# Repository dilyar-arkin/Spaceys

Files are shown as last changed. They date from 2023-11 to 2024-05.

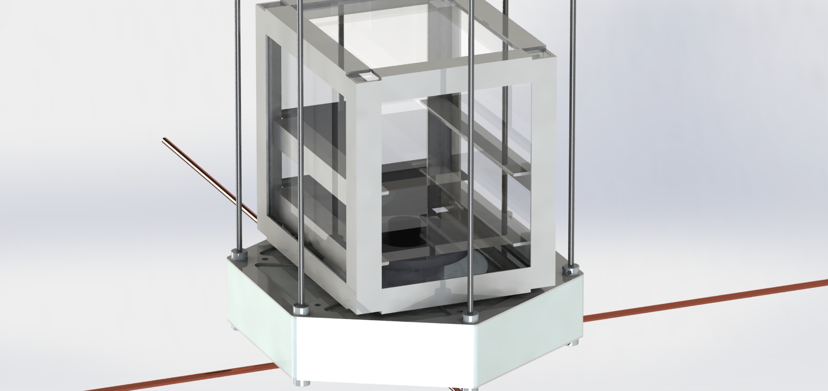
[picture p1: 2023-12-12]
Images/preview04.JPG

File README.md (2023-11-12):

# Spaceys
High Altitude RF Transmission Project

## Milestone 1
### On Board Sensor Integration 
To aquire data from following sensors and save them on micro SD card  via Raspberry Pi. 
* Gyroscope integration
* Thermocouple integration
* Pressure sensor integration

### CAD Modelling
* Assembly model for polycarbonate box
* Bill of materials for structural parts
* mock up 3D models for electronics components within the assembly
* mock up model for dipole antennas incl. supporing parts
* insulation layers both inner and outer

## Milestone 2
### Risk Analysis
* Fill up form:  CSA-STRATOS-FORM-0010_rev_IR_-_SEB_PAYLAOD_QT
### Software Defined Radio
* setup HackRF to receive FM radio stations
* Setup radiating element in the lab by signal generator, receiving signal on HackRF
* get familiar with bandpass filters, attunuation, and other aspacts of SDR
### Payload Safety Control 
* integrate heating and cooling devices into the payload for temperature control
* add event driven temperature / pressure control software functions to activate heaters/coolers
* thermal analysis on transfer layers to optimize shielding electronics from extreme environment  

## Milestone 3
### Transmitter RF Design and Development
* Signal generation - define equipment type specs
* RF amplifier - can handle output power level from signal generator and outputs 50 watts or higher Tx power
* Antenna impedance matching with the internal electronics. (antenna tuning)
* Design/Fabtication/Installation of the transmitter antenna module (50 ohms internal impedance)
* integrate Tx antenna into payload box, mounting and assembling
* Testing for weather, impact, shock (mechanical testing)
* Testing for beam forms, attenuation, gain, signal strength and more (electronic testing)

## Milestone 4
### Receiver RF - Ground Station Design and Development
* Rx antenna design and development (mechanical structure, impedance matching, gain ...)
* Antenna to Hack RF integration
* Software development (noise filtering, analog to digital conversion, frequency domain analysis ...)
* Modularity (ease of transport, palican case storage)

## Milestone 5
### Mechanical Testing
### Electrical Testing
### Software Testing
### RF Signal Range Testing

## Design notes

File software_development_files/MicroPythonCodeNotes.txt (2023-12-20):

SPACEY's MicroPython Code Notes
Michael Burns

i2c

from machine import Pin, I2C

i2c = I2C(0, scl=Pin(9), sda=Pin(8), freq=100000) 
i2c.scan()
i2c.writeto(76, b'123')
i2c.readfrom(76, 4)

i2c = I2C(1, scl=Pin(7), sda=Pin(6), freq=100000)
i2c.scan()
i2c.writeto_mem(76, 6, b'456')
i2c.readfrom_mem(76, 6, 4)

adc temperature

import machine
import utime

sensor_temp = machine.ADC(4)
conversion_factor = 3.3 / (65535)

while True:
    reading = sensor_temp.read_u16() * conversion_factor
    
    # The temperature sensor measures the Vbe voltage of a biased bipolar diode, connected to the fifth ADC channel
    # Typically, Vbe = 0.706V at 27 degrees C, with a slope of -1.721mV (0.001721) per degree. 
    temperature = 27 - (reading - 0.706)/0.001721
    print(temperature)
    utime.sleep(2)

Preliminary code attempt for sensor data collection based on the above example code.

import machine
import utime
from machine import Pin, I2C   #Imported relevant libraries and packages. 

#Code attempt for Pololu Gyro sensor connected to the first and second GPIO pins (I2C0 SDA) and (I2C0 SCL), respectively. 
i2c = I2C(0, scl=Pin(1), sda=Pin(0), freq=100)
i2c.scan()
i2c.writeto(76, b'123')  #Id like to look up the call sequence for these later for the significance of the 76 and the b'123'.
i2c.readfrom(76, 4)

#Code attempt for BMP 280 Pressure Sensor connected to the fourth and fifth GPIO pins (I2C1 SDA) and (I2C1 SCL), respectively.
i2c = I2C(1, scl=Pin(4), sda=Pin(3), freq=100)
i2c.scan()
i2c.writeto_mem(76, 6, b'456')
i2c.readfrom_mem(76, 6, 4)

#Code attempt for the temperature sensor connected to the 31st GPIO pin (ADC0). 
sensor_temp = machine.ADC(0)
conversion_factor = 3.3 / (65535)

while True;
    reading = sensor_temp.read_u16() * conversion_factor
    
    #Measuring the Vbe voltage of the diode, connected to the first ADC channel.
    #From example code; usually Vbe = 0.706V at 27 degrees C, with a slope of -1.721mV per degree.
    temperature = 27 - (reading - 0.706)/0.001721
    print(temperature)
    utime.sleep(2)

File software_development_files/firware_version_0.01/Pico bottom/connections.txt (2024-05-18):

-big SD
-gyroscope sensor
-temperature sensor connected to the Peltier cooler: GPIO28
-temperature sensor: GPIO27
-relay

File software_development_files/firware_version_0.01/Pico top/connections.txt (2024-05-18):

-microSD
-BMP280 pressure sensor
-temperature sensor: GPIO 26
-temperature sensor: GPIO 22

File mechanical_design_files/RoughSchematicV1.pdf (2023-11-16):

1* 30":T'#
1l-''

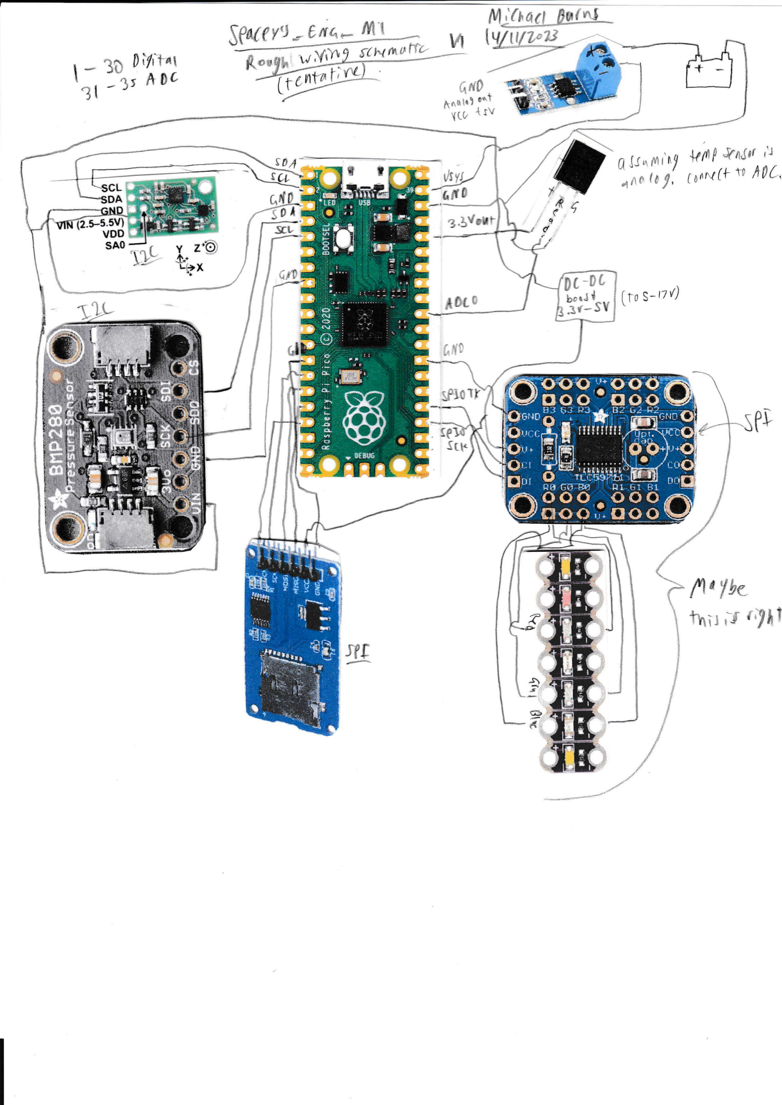
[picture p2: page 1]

## TPa{f v'i - {rt{^* ffi.1

L)\ - *' | -*- | :

### SD A- <':: lar \t

## c4!: r'To I t

Yr

scL i

it flU 'I
trnuhl Git
{(-0 I sv

&,r0
3.5{c*r

## t0r c

### fi JJ o rrr i't/

,{ne fdf,

kdf *Fn,jcr r)
66rrM(t \il A0L,

Dt -0[
bcrJ { (to s-iz'r)
.:r-5Y

: ".,.
!\

# rricrl

.5ri
{e
5rF

(
F nd Y&*-

## %i: ;g {'f &?

A

{B

## zts

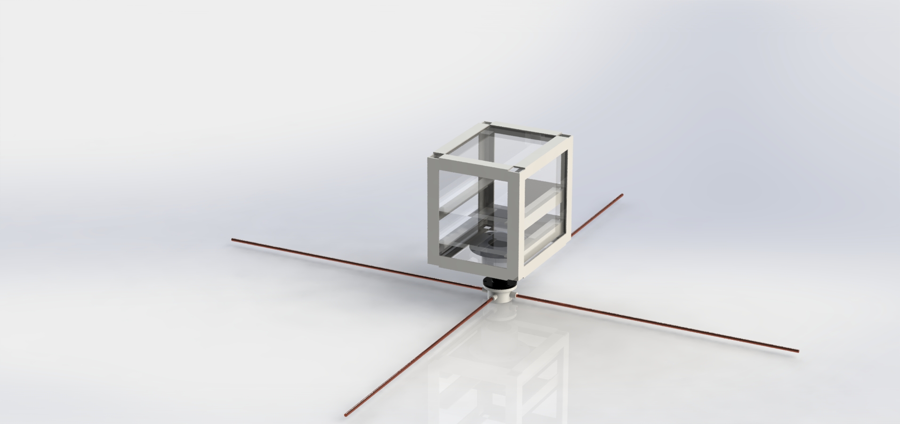
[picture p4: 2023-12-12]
Images/preview01.JPG

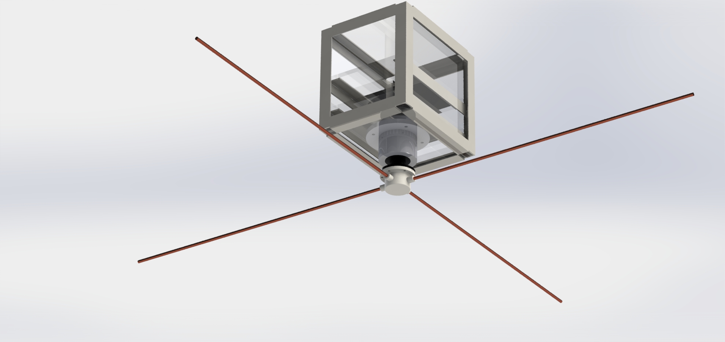
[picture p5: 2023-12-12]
Images/preview02.JPG

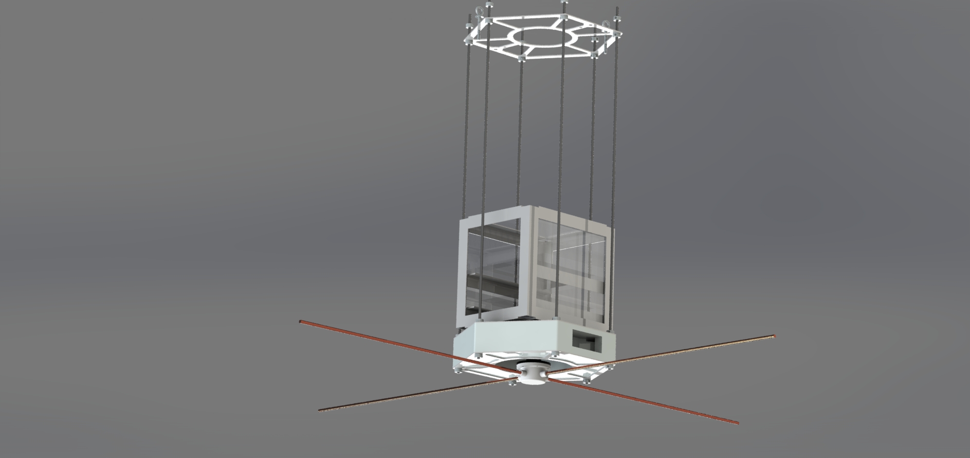
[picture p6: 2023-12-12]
Images/preview05.JPG

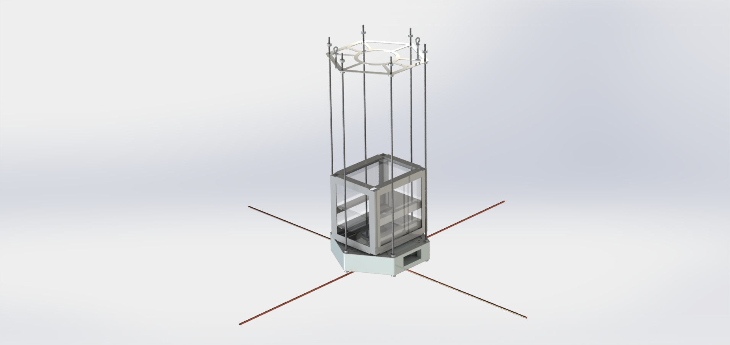
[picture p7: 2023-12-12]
Images/preview03.JPG

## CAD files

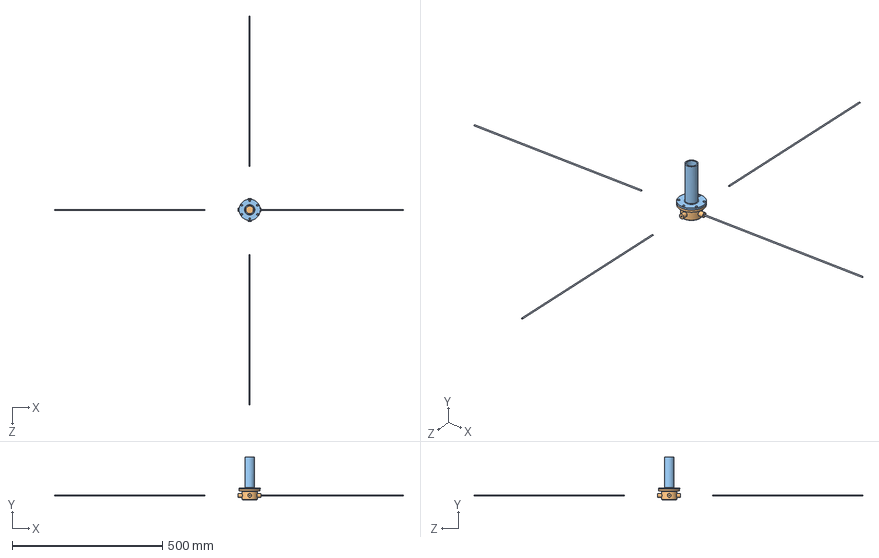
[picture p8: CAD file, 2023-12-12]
mechanical_design_files/CAD model/antenna_housing_assem.SLDASM
1160.0 x 141.3 x 1291.8 mm
connector_arm
four_way_antennaHousing
radiating_element x 4

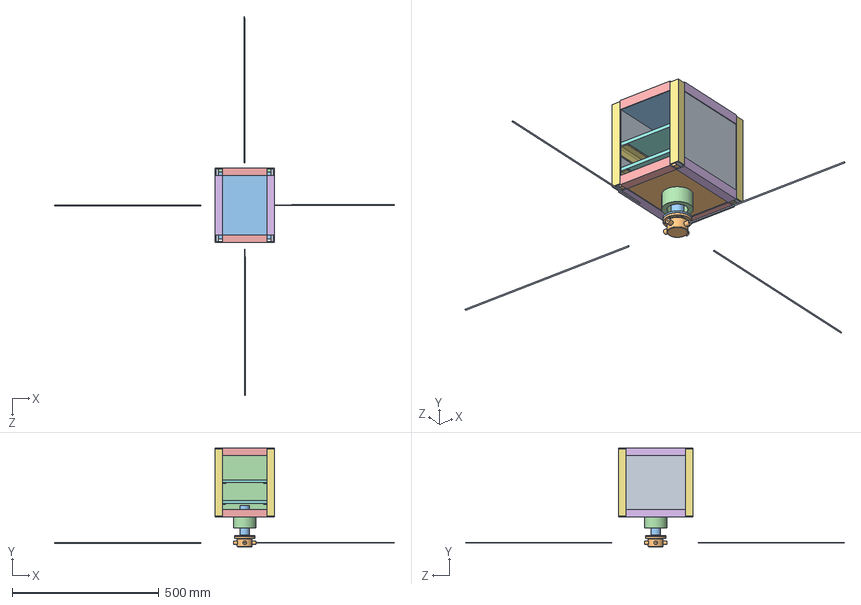
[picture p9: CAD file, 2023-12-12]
mechanical_design_files/CAD model/box_assembly.SLDASM
1160.0 x 337.3 x 1291.8 mm
cover_side
cover_top
cover_bottom
cover_side_long x 2
layer_base_plate x 2
8982K131_Multipurpose 6061 Aluminum 90 Degree Angle x 8
8982K131_Multipurpose 6061 Aluminum 90 Degree Angle_10inch_customCut x 4
8982K131_Multipurpose 6061 Aluminum 90 Degree Angle_8inch_customCut x 4
antenna_mount_bushing
connector_arm
four_way_antennaHousing
radiating_element x 4

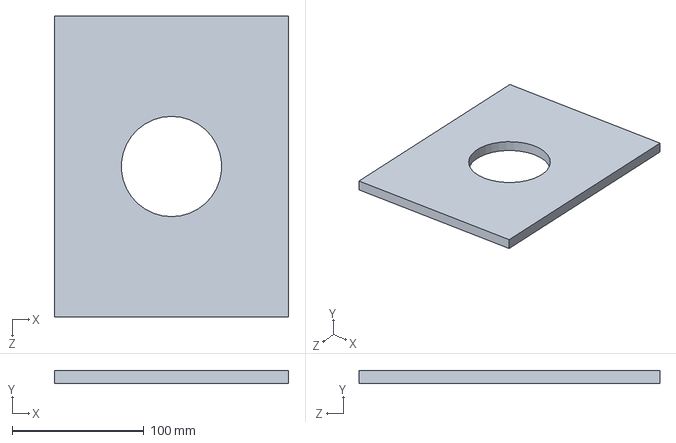
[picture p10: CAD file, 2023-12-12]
mechanical_design_files/CAD model/cover_bottom.SLDPRT
177.8 x 9.53 x 228.6 mm

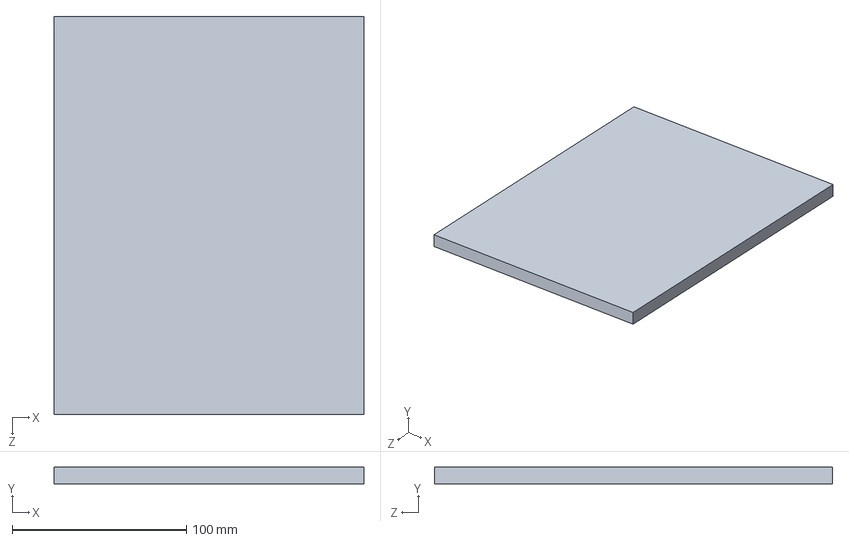
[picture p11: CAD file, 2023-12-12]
mechanical_design_files/CAD model/cover_top.SLDPRT
177.8 x 9.53 x 228.6 mm

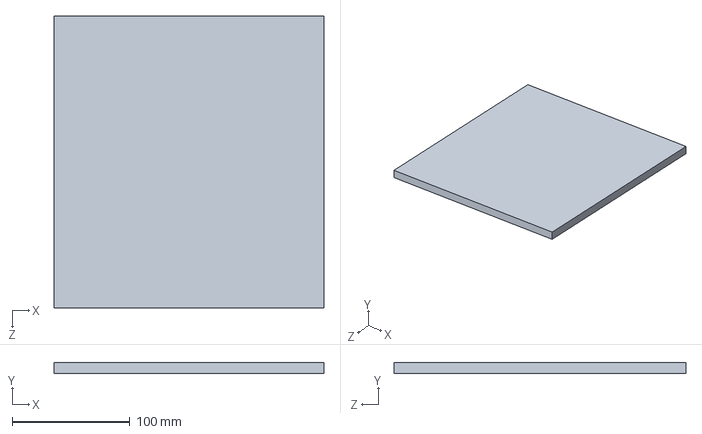
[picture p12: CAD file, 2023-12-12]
mechanical_design_files/CAD model/cover_side_long.SLDPRT
228.6 x 9.53 x 247.6 mm

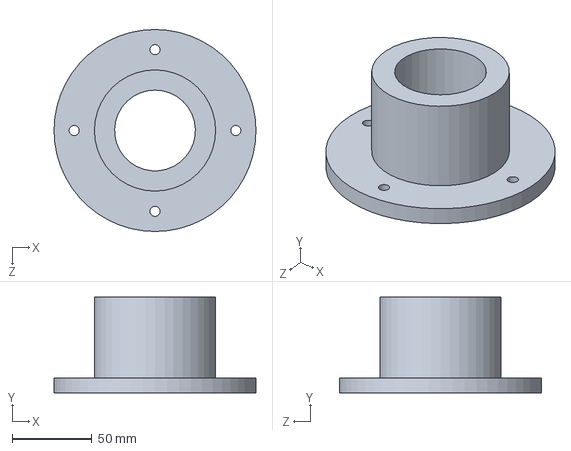
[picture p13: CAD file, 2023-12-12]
mechanical_design_files/CAD model/antenna_mount_bushing.SLDPRT
127.0 x 60.3 x 127.0 mm

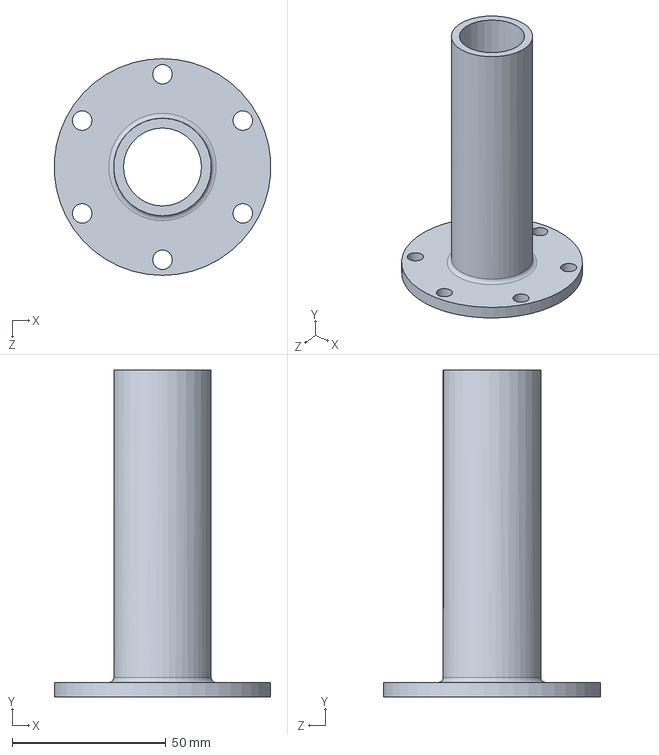
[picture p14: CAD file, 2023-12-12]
mechanical_design_files/CAD model/connector_arm.SLDPRT
70.3 x 106.4 x 70.5 mm

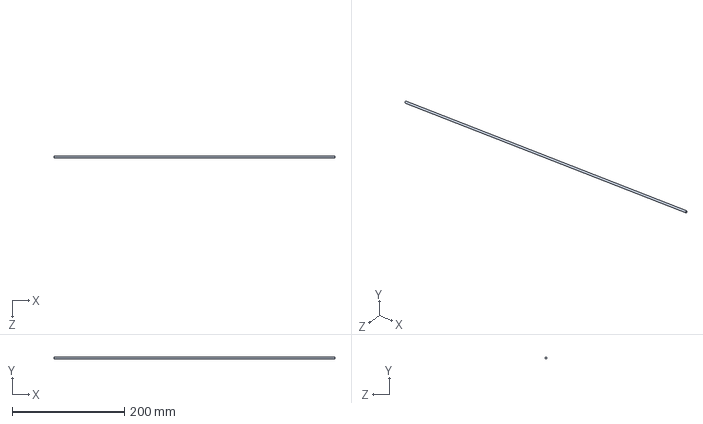
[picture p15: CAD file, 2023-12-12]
mechanical_design_files/CAD model/radiating_element.SLDPRT
500.0 x 3.17 x 3.17 mm

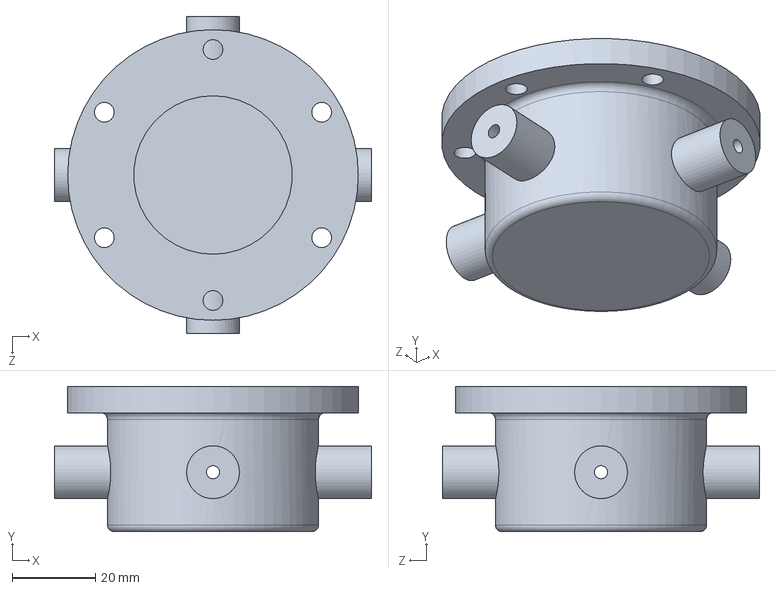
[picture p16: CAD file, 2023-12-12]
mechanical_design_files/CAD model/four_way_antennaHousing.SLDPRT
76.2 x 34.9 x 76.2 mm

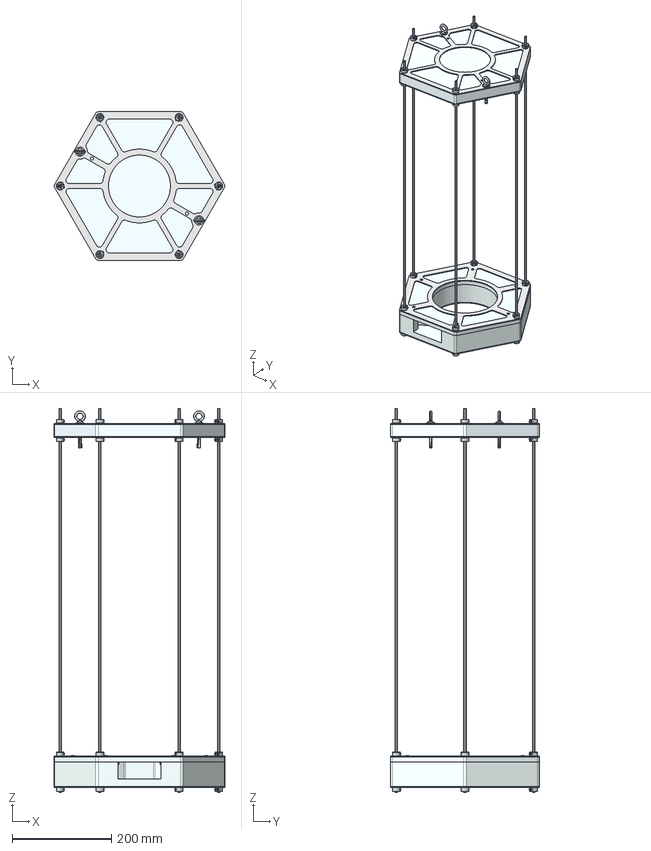
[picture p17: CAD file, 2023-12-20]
mechanical_design_files/CAD model/20231108 - SEB Payload Bay STPs/20231108_SEB_Payload_Bay_Nadir.stp
344.4 x 300.0 x 775.0 mm
08 - Power System - Foam Base
08 - Power System - Support Plate - Nadir
08 - Power System - Foam Lid
08 - Avionics Gondola - Foam Base
08 - Avionics Gondola - Mid Plate x 2
08 - CF Rod - 775mm x 6
08 - Collar x 24
09 - Washer - M6 x 2
09 - Eye Bolt - M6-1x51 x 2
08 - Payload Interface Plate - Nadir
09 - Rivet Nut - M4-0.7 x 6

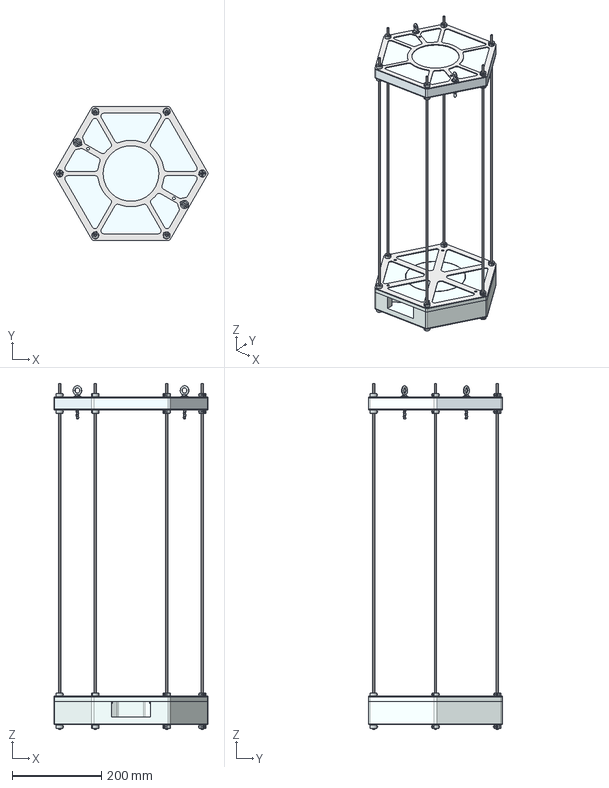
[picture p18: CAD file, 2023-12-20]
mechanical_design_files/CAD model/20231108 - SEB Payload Bay STPs/20231108_SEB_Payload_Bay_Blind_Bolted.stp
344.3 x 300.0 x 775.0 mm
09 - Rivet Nut - M4-0.7 x 6
08 - Payload Interface Plate - Blind Bolted
08 - Power System - Foam Base
08 - Power System - Support Plate - Blind
08 - Power System - Foam Lid
08 - Power System - Foam Filler
08 - Avionics Gondola - Foam Base
08 - Avionics Gondola - Mid Plate x 2
08 - CF Rod - 775mm x 6
08 - Collar x 24
09 - Washer - M6 x 4
09 - Eye Bolt - M6-1x51 x 2
09 - Nut - M6-1 x 2

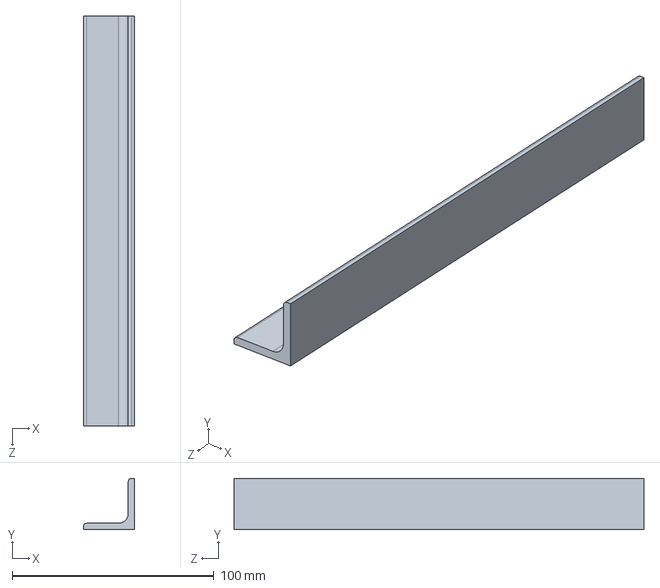
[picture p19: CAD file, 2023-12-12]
mechanical_design_files/CAD model/8982K131_Multipurpose 6061 Aluminum 90 Degree Angle_10inch_customCut.SLDPRT
25.4 x 25.4 x 203.2 mm

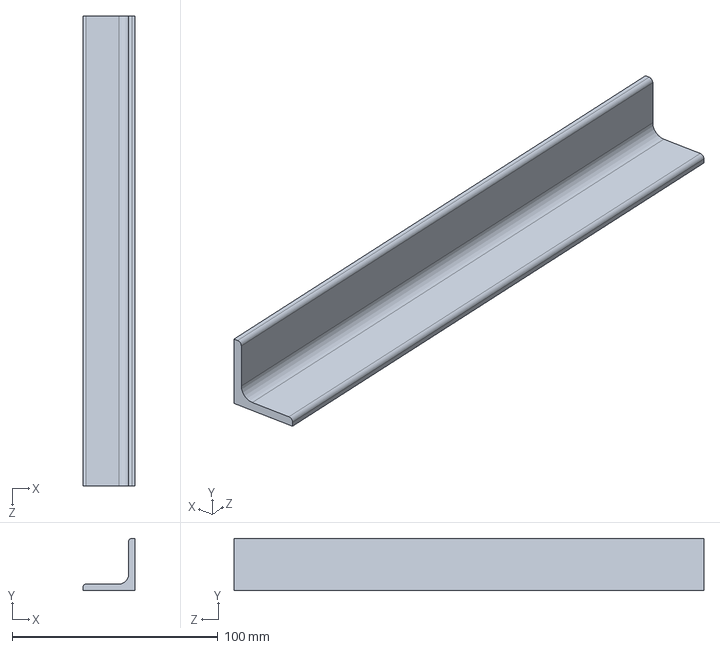
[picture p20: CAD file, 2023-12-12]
mechanical_design_files/CAD model/8982K131_Multipurpose 6061 Aluminum 90 Degree Angle.SLDPRT
25.4 x 25.4 x 228.6 mm

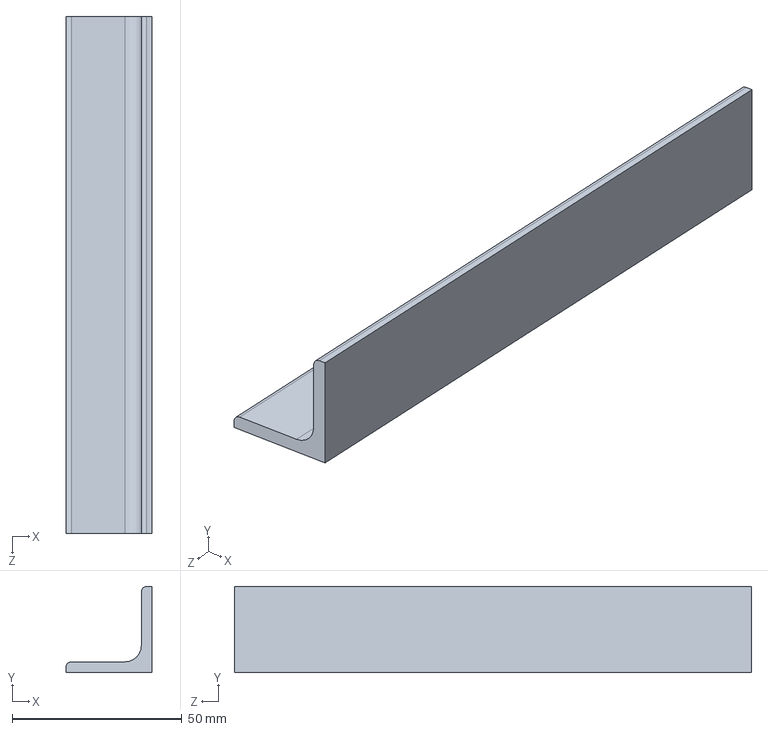
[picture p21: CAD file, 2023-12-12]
mechanical_design_files/CAD model/8982K131_Multipurpose 6061 Aluminum 90 Degree Angle_8inch_customCut.SLDPRT
25.4 x 25.4 x 152.4 mm

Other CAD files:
mechanical_design_files/CAD model/layer_base_plate.SLDPRT
mechanical_design_files/CAD model/cover_side.SLDPRT
mechanical_design_files/CAD model/20231108 - SEB Payload Bay STPs/20231108_SEB_Payload_Bay_Blind.stp

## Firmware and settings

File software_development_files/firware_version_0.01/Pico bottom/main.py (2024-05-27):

from machine import ADC, Pin, I2C
from time import *
#import os
#import uos
import asyncio
from sdcard_init_class import sdcard_init
from sdcard import SDCard
from imu import MPU6050
from temperature_reader import *
from relay import *
from rf_driver_controller import *
from peltier_cooler import *
from logging import *

"""Define global variables"""
global RF_DRIVER_TEMP_SENSOR_PIN
RF_DRIVER_TEMP_SENSOR_PIN = 27 #ADC pin for RF driver temperature sensor- data saved to SD
global TEMP_SENSOR2_PIN
TEMP_SENSOR2_PIN = 28 #ADC pin for temperature sensor connected to Peltier cooler- data saved to SD
global PELTIER_PIN
PELTIER_PIN = Pin(20, Pin.OUT) #GPIO pin controlling Peltier cooler
global RF_DRIVER_PIN
RF_DRIVER_PIN = Pin(17, Pin.OUT) #GPIO pin controlling RF driver

"""Configure logging to write to a text file on the Raspberry Pi"""
logger2 = getLogger()
logger2.setLevel(DEBUG)
file_handler = FileHandler("error_log.txt")
file_handler.setLevel(DEBUG)
formatter = Formatter("%(levelname)s:%(name)s:%(message)s")
file_handler.setFormatter(formatter)
logger2.addHandler(file_handler)

async def initialize():
    init_attempts = 0
    SD = None
    i2c0 = None
    imu = None
    rf_driver = None
    peltier = None
    temperature_sensor = None
    
    while init_attempts < 5:
        all_initialized = True
        try:
            """Initialize SD card (bigger)"""
            if not SD:
                try:
                    SD = sdcard_init(5,7,4,6,0)
                except Exception as e:
                    print("Error found initializing SD (bigger): ", e)
                    logger2.error("Error found initializing microSD: " + str(e))
                    all_initialized = False
        
            """Initialize I2C bus"""
            if not i2c0:
                try:
                    i2c0_sda = Pin(14)
                    i2c0_scl = Pin(15)
                    i2c0 = I2C(1, sda=i2c0_sda, scl=i2c0_scl, freq=400000)
                except Exception as e:
                    print("Error found initializing I2C bus: ", e);
                    logger2.error("Error found initializing I2C bus: %s" + str(e))
                    all_initialized = False
        
            """Initialize IMU"""
            if not imu:
                try:
                    imu = MPU6050(i2c0)
                except Exception as e:
                    print("Error found initializing I2C bus: ", e);
                    logger2.error("Error found initializing I2C bus: %s" + str(e))
                    all_initialized = False
            
            if all_initialized:
                #Create instances of RF driver and Peltier cooler
                rf_driver = rf_driver_controller(RF_DRIVER_PIN)
                peltier = peltier_cooler(PELTIER_PIN)
                #Create an instance of temperature_reader for temperature sensor 2 and RF driver's temperature sensor
                temperature_sensor = temperature_reader()
                return SD, i2c0, imu, rf_driver, peltier, temperature_sensor
        except Exception as e:
            print(f"Unexpected error during initialization: {e}")
            logger2.error(f"Unexpected error during initialization: {e}")
        
        init_attempts += 1
        print(f"Initialization attempt {init_attempts} failed. Retrying...")
        logger2.error(f"Initialization attempt {init_attempts} failed.")
        sleep(1)  # Wait before retrying
        
    """Create instances of RF driver and Peltier cooler"""
    #Objects are created regardless of the initialization status of SD card and IMU
    #Working combinations: SD initialized IMU initialized, SD initialized IMU not initialized
    rf_driver = rf_driver_controller(RF_DRIVER_PIN)
    peltier = peltier_cooler(PELTIER_PIN)
    #Create an instance of temperature_reader for temperature sensor 2 and RF driver's temperature sensor
    temperature_sensor = temperature_reader()
    
    print(f"Failed to initialize after {init_attempts} attempts but proceeded returned values if any.")
    logger2.error(f"Failed to initialize after {init_attempts} attempts but proceeded with returned values if any.")
    return SD, i2c0, imu, rf_driver, peltier, temperature_sensor

async def rf_driver_temperature_check(SD, rf_driver, peltier, temperature_sensor):
    """Check RF driver temperature and adjust Peltier cooler if necessary"""
    while True:
        try:
            #Read RF driver temperature
            rf_driver_temp_data = temperature_sensor.read_temperature(RF_DRIVER_TEMP_SENSOR_PIN)
            #Temperature condition check- control Peltier cooler based on RF driver's temperature
            if 40 < rf_driver_temp_data < 80:
                peltier.turn_on_peltier()
            elif rf_driver_temp_data > 80:
                rf_driver.turn_off_rf_driver()
                #Turn off PLL simultaneously - insert statement here
                raise SystemExit
            #Write RF driver's temperature data to SD card
            if rf_driver_temp_data is not None:
                SD.write("RF Driver Temperature", f"Temperature: {rf_driver_temp_data}")
        except Exception as e:
            print("Error occurred during temperature condition check and adjusting Peltier cooler and/or turning off RF driver:", e)
            raise SystemExit
        await asyncio.sleep(1)

async def temperature_sensor_reading(SD, temperature_sensor):
    """Read data from temperature sensor 2 (connected to Peltier cooler)"""
    while True:
        try:
            #Read temperature values from temperature sensor 2 attached to SD (bigger) and connected to Peltier
            temperature_sensor2_data = temperature_sensor.read_temperature(TEMP_SENSOR2_PIN)
            #Write temperature data to text file in SD card
            if temperature_sensor2_data is not None:
                SD.write("Temperature Sensor 2-(Peltier)-Data", f"Temperature: {temperature_sensor2_data}")
        except Exception as e:
            print("Error found reading and/or writing temperature data from temperature sensor 2 connected to Peltier cooler (saved to SD)", e)
            raise SystemExit
        await asyncio.sleep(1)
              
async def gyroscope_reading(SD, imu):
    """Read and save gyroscope data"""
    while True:
        try:
            #Read gyroscope values
            gx = round(imu.gyro.x)
            gy = round(imu.gyro.y)
            gz = round(imu.gyro.z)
            tem = round(imu.temperature, 2)        
            #Write gyroscope data to SD card
            SD.write("Gyroscope_Data", f"GX: {gx}, GY: {gy}, GZ: {gz}, Temperature: {tem}")
        except Exception as e:
            print("Error occurred during gyroscope data reading and/or writing to SD card:", e)
            raise SystemExit
        await asyncio.sleep(1)

async def check_relay():
    """Check the relay status and turn off PLL if relay is off"""
    #Initialize relay failure status
    relay.initialize_relay_failure_status() #relay status is up-to-date each time the coroutine is invoked
    if relay.is_relay_failure():
        #Turn off PLL
        raise SystemExit
    await asyncio.sleep(300)  #Wait for 5 minutes before checking again

async def main():
    SD, i2c0, imu, rf_driver, peltier, temperature_sensor = await initialize()  
    
    #Turn on RF driver in the beginnging
    rf_driver.turn_on_rf_driver()  #RF driver runs continuously - 1 Watt
    #Turn on the pll after the RF is on - insert statement here
    
    tasks = []
    #Add tasks based on initialization combinations
    if SD and imu:
        tasks.extend([
            rf_driver_temperature_check(SD, rf_driver, peltier, temperature_sensor),
            temperature_sensor_reading(SD, temperature_sensor),
            gyroscope_reading(SD, imu),
        ])
        
    elif SD:
        tasks.extend([
            rf_driver_temperature_check(SD, rf_driver, peltier, temperature_sensor),
            temperature_sensor_reading(SD, temperature_sensor),
            ])
    else:
        rf_driver.turn_off_rf_driver()
        #Turn off PLL simultaneously- insert statement here
        raise SystemExit
    
    #Check relay status continuously
    relay_check_task = asyncio.create_task(check_relay())  #every 5 min
    
    #Wait for tasks to complete
    await asyncio.gather(*tasks)
    await relay_check_task  #Ensure relay checking task is also completed
    
if __name__ == "__main__":
    asyncio.run(main())

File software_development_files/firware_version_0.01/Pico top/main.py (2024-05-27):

import machine
from machine import Pin, I2C
from time import sleep
#import os
#import uos
from bmp280_i2c import BMP280I2C
from bmp280_configuration import BMP280Configuration
from bmp280_init_class import *
from sdcard_init_class import *
from temperature_reader import *
from logging import *

"""Define global variables"""
global TEMP_SENSOR3_PIN 
TEMP_SENSOR3_PIN = 27 #ADC pin for temperature sensor 3- microSD
global TEMP_SENSOR4_PIN
TEMP_SENSOR4_PIN = 26 #ADC pin for temperature sensor 4- microSD

"""Configure logging to write to a text file on the Raspberry Pi"""
logger = getLogger()
logger.setLevel(DEBUG)
file_handler = FileHandler("error_log.txt")
file_handler.setLevel(DEBUG)
formatter = Formatter("%(levelname)s:%(name)s:%(message)s")
file_handler.setFormatter(formatter)
logger.addHandler(file_handler)

def initialize():
    init_attempts = 0
    microSD = None
    bmp280_i2c = None
    i2c0 = None
    
    while init_attempts < 5:
        all_initialized = True
        try:
            """Initialize microSD card"""
            if not microSD:
                try: 
                    microSD = sdcard_init(13,11,12,10,1)
                except Exception as e:
                    print("Error found initializing microSD: ", e)
                    logger.error("Error found initializing microSD: " + str(e))
                    all_initialized = False
            
            """Initialize I2C bus"""
            if not i2c0:
                try: 
                    i2c0_sda = Pin(2)
                    i2c0_scl = Pin(3)
                    i2c0 = I2C(1, sda=i2c0_sda, scl=i2c0_scl, freq=400000)
                except Exception as e:
                    print("Error found initializing I2C bus: ", e);
                    logger.error("Error found initializing I2C bus: %s" + str(e))
                    all_initialized = False
            
            """Initialize BMP280 sensor"""
            if not bmp280_i2c and i2c0:
                try: 
                    bmp280_i2c = BMP280I2C(0x77, i2c0)
                except Exception as e:
                    print("Error found initializing BMP280 sensor: ",e);
                    logger.error("Error found initializing BMP280 sensor: " + str(e))
                    all_initialized = False
                
            if all_initialized:
                return microSD, i2c0, bmp280_i2c
            
        except Exception as e:
            print(f"Unexpected error during initialization: {e}")
            logger.error(f"Unexpected error during initialization: {e}")
            
        init_attempts += 1
        print(f"Initialization attempt {init_attempts} failed. Retrying...")
        logger.error(f"Initialization attempt {init_attempts} failed.")
        sleep(1)  # Wait before retrying
        
    print(f"Failed to initialize after {init_attempts} attempts but proceeded with returned values if any.")
    logger.error(f"Failed to initialize after {init_attempts} attempts but proceeded with returned values if any.")
    return microSD, i2c0, bmp280_i2c
            
def main():
    
    microSD, i2c0, bmp280_i2c = initialize()
    
    #Create an instance of temperature_reader for each temperature sensor
    temperature_sensor = temperature_reader()

    while True:
        """Read and save BMP280 data"""
        if bmp280_i2c is not None and microSD is None:
            raise SystemExit
        if bmp280_i2c is not None: #If BMP280 sensor and microSD are both initialized
            try:
                #Read temperature and pressure values from BMP280 sensor
                readout = bmp280_i2c.measurements
                temperature_c = round(readout['t'], 2);
                pressure_hpa = round(readout['p'], 2);
                #Write BMP280 temperature and pressure data to different text files
                microSD.write("BMP280 Sensor-Temperature", temperature_c)
                microSD.write("BMP280 Sensor-Pressure", pressure_hpa)
            except Exception as e:
                print("Error found reading and/or writing BMP 280 sensor (temperature and pressure) data", e);
                logger.error("Error found reading and/or writing BMP280 sensor (temperature and pressure) data: " + str(e))
            finally:
                sleep(1); #Delay for 1 sec between readings
        
        """Read and save temperature values from temp. sensors 3 and 4"""
        if microSD is not None: #If microSD card is initialized
            try:
                #Read temperature values from temperature sensors attached to microSD
                temperature_sensor3_data = temperature_sensor.read_temperature(TEMP_SENSOR3_PIN)
                temperature_sensor4_data = temperature_sensor.read_temperature(TEMP_SENSOR4_PIN)
                #Write temperature data to text files in microSD card
                if temperature_sensor3_data is not None:
                    microSD.write("Temperature Sensor 3-Data", temperature_sensor3_data)
                if temperature_sensor4_data is not None:
                    microSD.write("Temperature Sensor 4-Data", temperature_sensor4_data)
            except Exception as e:
                print("Error found reading and/or writing temperature data from temperature sensor 3 and 4 (connected to microSD)", e)
                logger.error("Error found reading and/or writing temperature data from temperature sensor 3 and 4 (connected to microSD): " + str(e))
            finally:
                sleep(1) #Delay for 1 sec between readings  
        else:
            raise SystemExit

if __name__ == "__main__":
    main()

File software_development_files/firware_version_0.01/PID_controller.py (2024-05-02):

#Regulating the temperature with PID- control algorithm
#pid = PIDController(Kp=1.0, Ki=0.1, Kd=0.01, setpoint=desired_temperature)
#Kp = proportional gain, Ki = integral gain, Kd = derivative gain, de/dt

class PID_Controller:
    def __init__(self):
        self.Kp = #Kp 
        self.Ki = #Ki
        self.Kd = #Kd
        self.setpoint = #Desired temperature
        self.previous_error = 0
        self.integral = 0

    def calculate(self, temperature):
        error = self.setpoint - temperature
        self.integral += error
        derivative = error - self.previous_error
        output = self.Kp * error + self.Ki * self.integral + self.Kd * derivative
        self.previous_error = error
        return output

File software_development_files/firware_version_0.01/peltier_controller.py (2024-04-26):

from machine import Pin, ADC
import time

#peltier_pin = Pin(21, Pin.OUT)  #GPIO pin controlling Peltier cooler
#temp_sensor_pin = 28            #ADC pin for temperature sensor

#AMBIENT_TEMP_THRESHOLD_LOW = 0   #Lower temperature threshold for normal operation
#AMBIENT_TEMP_THRESHOLD_HIGH = 40  #Upper temperature threshold for normal operation
#VERY_HIGH_TEMP_THRESHOLD = 80

class peltier_controller:
    def __init__(self, peltier_pin, temp_sensor_pin):
        self.peltier_pin = Pin(peltier_pin, Pin.OUT)
        self.temp_sensor_pin = ADC(temp_sensor_pin)

    def reset_pins(self):
        """Reset GPIO pins."""
        gpio_pin_list = range(16, 23)  #Excluding pin 23
        for i in gpio_pin_list:
            gpio_pin = Pin(i, Pin.OUT)
            gpio_pin.on()  #Pin is actually off, no current

    def read_temperature(self):
        """Read temperature from ADC."""
        try:
            temp_adc = ADC(self.temp_sensor_pin)
            adc_value = temp_adc.read_u16()
            volt = (3.3 / 65535) * adc_value
            temperature_celsius = (100 * volt) - 50
            return temperature_celsius
        except Exception as e:
            print("Error found reading sensor data/ calculating:", e)
            return None

    def control_peltier_cooler(self):
        """Control Peltier cooler based on temperature."""
        try:
            while True:
                temperature = self.read_temperature()
                print("Temperature:", temperature, "C")
                time.sleep(1)  #Sleep for 1 second before reading temperature again
        except KeyboardInterrupt:
            pass  #Exit, if interrupted
    
    def turn_on(self):
        """Turn on the Peltier cooler."""
        self.peltier_pin.off()
        print("Peltier cooler turned on.")

    def turn_off(self):
        """Turn off the Peltier cooler."""
        self.peltier_pin.on()
        print("Peltier cooler turned off.")

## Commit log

2023-11-16 Add files via upload
    This is the rough schematic I put together last night just by printing out the images of the components, sticking them down to paper, and drawing the connections between them. I shared it on Discord,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
2023-11-16 Add files via upload
    I looked up on https://docs.micropython.org/en/latest/library/index.html#libraries-specific-to-the-rp2040 to start learning the coding, and it linked me to another github with a bunch of example code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
2023-12-20 documents upload
    [20231108_SEB_Payload_Bay_Blind.stp, 20231108_SEB_Payload_Bay_Blind_Bolted.stp, 20231108_SEB_Payload_Bay_Nadir.stp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]
2024-01-29 sensor to sd card read/store complete
2024-03-02 update to gyro_test.py
2024-03-07 adding main.py and calibration.py
2024-03-08 update main_extended.py in test cases
    i added a for loop to activate/deactivate cooler depending on the temperature. inside while loop.
2024-03-28 relay test case added
2024-03-29 update relay
2024-03-29 update amplifier, cooler, and add pin relay test
2024-04-05 upload imu.py, vector3d.py, updated sdcard_init_class.py
2024-04-26 upload main and required libraries
    main includes the temperature correction mode, normal mode, and relay check
    [main.py, peltier_controller.py]
2024-04-30 editing relay_module.py library, editing main2.py, editing peltier_cooler.py library, and moving some libraries to firmware files
    editing relay_module.py library, editing main2.py, editing peltier_cooler.py library, and moving some libraries (vector3d.py, sdcard.py, imu.py) to firmware files
2024-05-02 update relay_module.py and main2.py, fixing relay bugs, and moving some files into the firmware folder
    [relay_module.py]
